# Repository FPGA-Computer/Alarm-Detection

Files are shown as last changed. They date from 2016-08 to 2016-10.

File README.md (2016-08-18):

"Alarm detection for hearing impaired"

This is the repository for this project.

Project page:
https://hackaday.io/project/12703

Schematic tool: Eagle CAD 6.5.0
3D modelling: Sketchup 14.1 2014

Licensing:
Schematic: Creative Commons 4.0 Attribution-ShareAlike 4.0 International
PCB & Layout: Creative Commons 4.0 Attribution-NonCommercial
3D modelling: Creative Commons 4.0 Attribution-ShareAlike 4.0 International

Creative Commons 4.0 Attribution-NonCommercial:
See http://creativecommons.org/licenses/by-nc/4.0/

Creative Commons 4.0 Attribution-ShareAlike 4.0 International
See http://creativecommons.org/licenses/by-sa/4.0/

Firmware license: GPL 3.0

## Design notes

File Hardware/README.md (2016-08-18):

"Alarm detection for hearing impaired"

Since the common block is useful for a few of my projects, 
I have splitted off the hardware design into smaller modular 
block for initial prototyping.

LCD Backpack: STM32F030 based PCB for mounting onto the back 
of a "Nokia" LCD.  It has anti-alias RC filter for ADC and an 
optional 3.3V boost mode power supply for running off two
Alkaline/NiMH batteries.

The firmware is based on the VU/Spectrum analyzer of the 
"Automatic-Audio-Switch".  I have increase the FFT resolution 
to about 37.5Hz and a bandwidth of 5kHz.

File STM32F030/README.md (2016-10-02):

Alarm detection for hearing impaired

"DMA mem func & reorg"
- use DMA for memset() and memmove()
- reorganize DMA, SPI calls from Nokia5110 into hardware.c
---------------------------------
"Visualization"
- added a simple graphic library
- added battery status and volume envelope
---------------------------------
"Lost in Space" pre-pre release
The PCB I have ordered has been lost in the mail.  This
is the 2nd one in a row and I don't know if/when they
would fix up the shipping.  This has major impact to the
schedule of this project.  Since there don't seem be much 
interest in this, I have decided to do an premptive
release of the firmware at the early stage.

Source code is under GPL3.0 with the following 3 files 
under their own licenses.

ST: startup_stm32f030.s
Elm-chan's: intfft.c, intfft.h

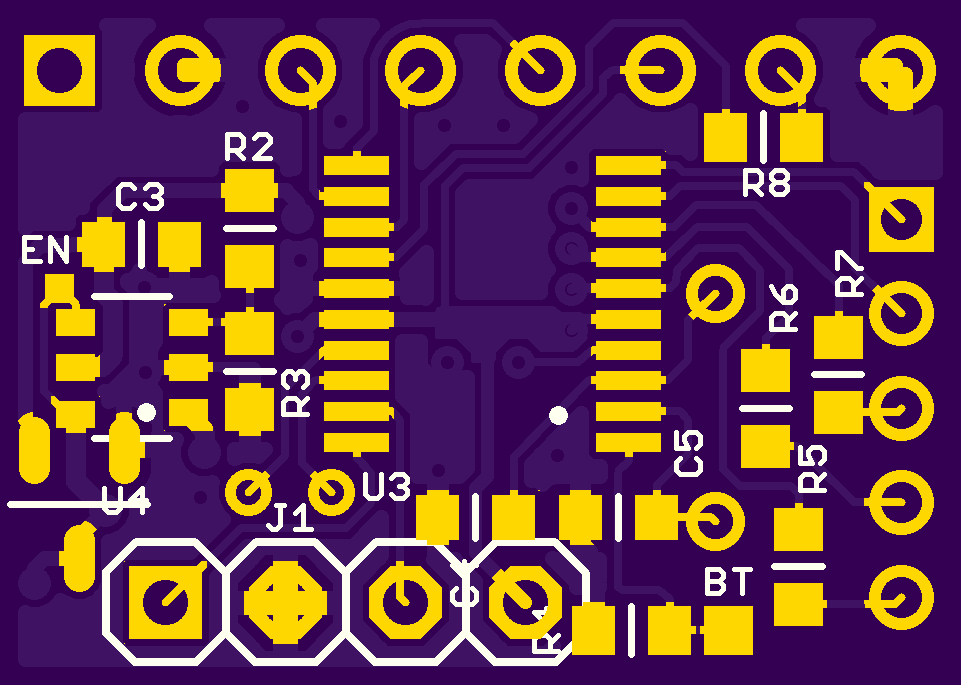
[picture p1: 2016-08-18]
Hardware/Prototype/LCD Backpack/eagleUp/eagleUp_alarm-v1_board_bottom.png

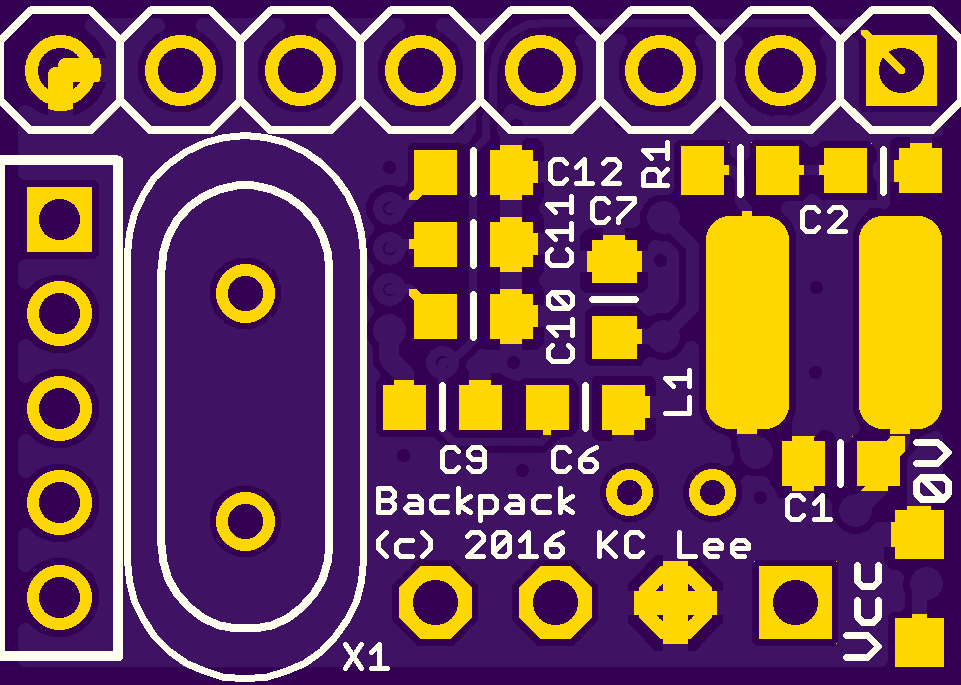
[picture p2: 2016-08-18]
Hardware/Prototype/LCD Backpack/eagleUp/eagleUp_alarm-v1_board_top.png

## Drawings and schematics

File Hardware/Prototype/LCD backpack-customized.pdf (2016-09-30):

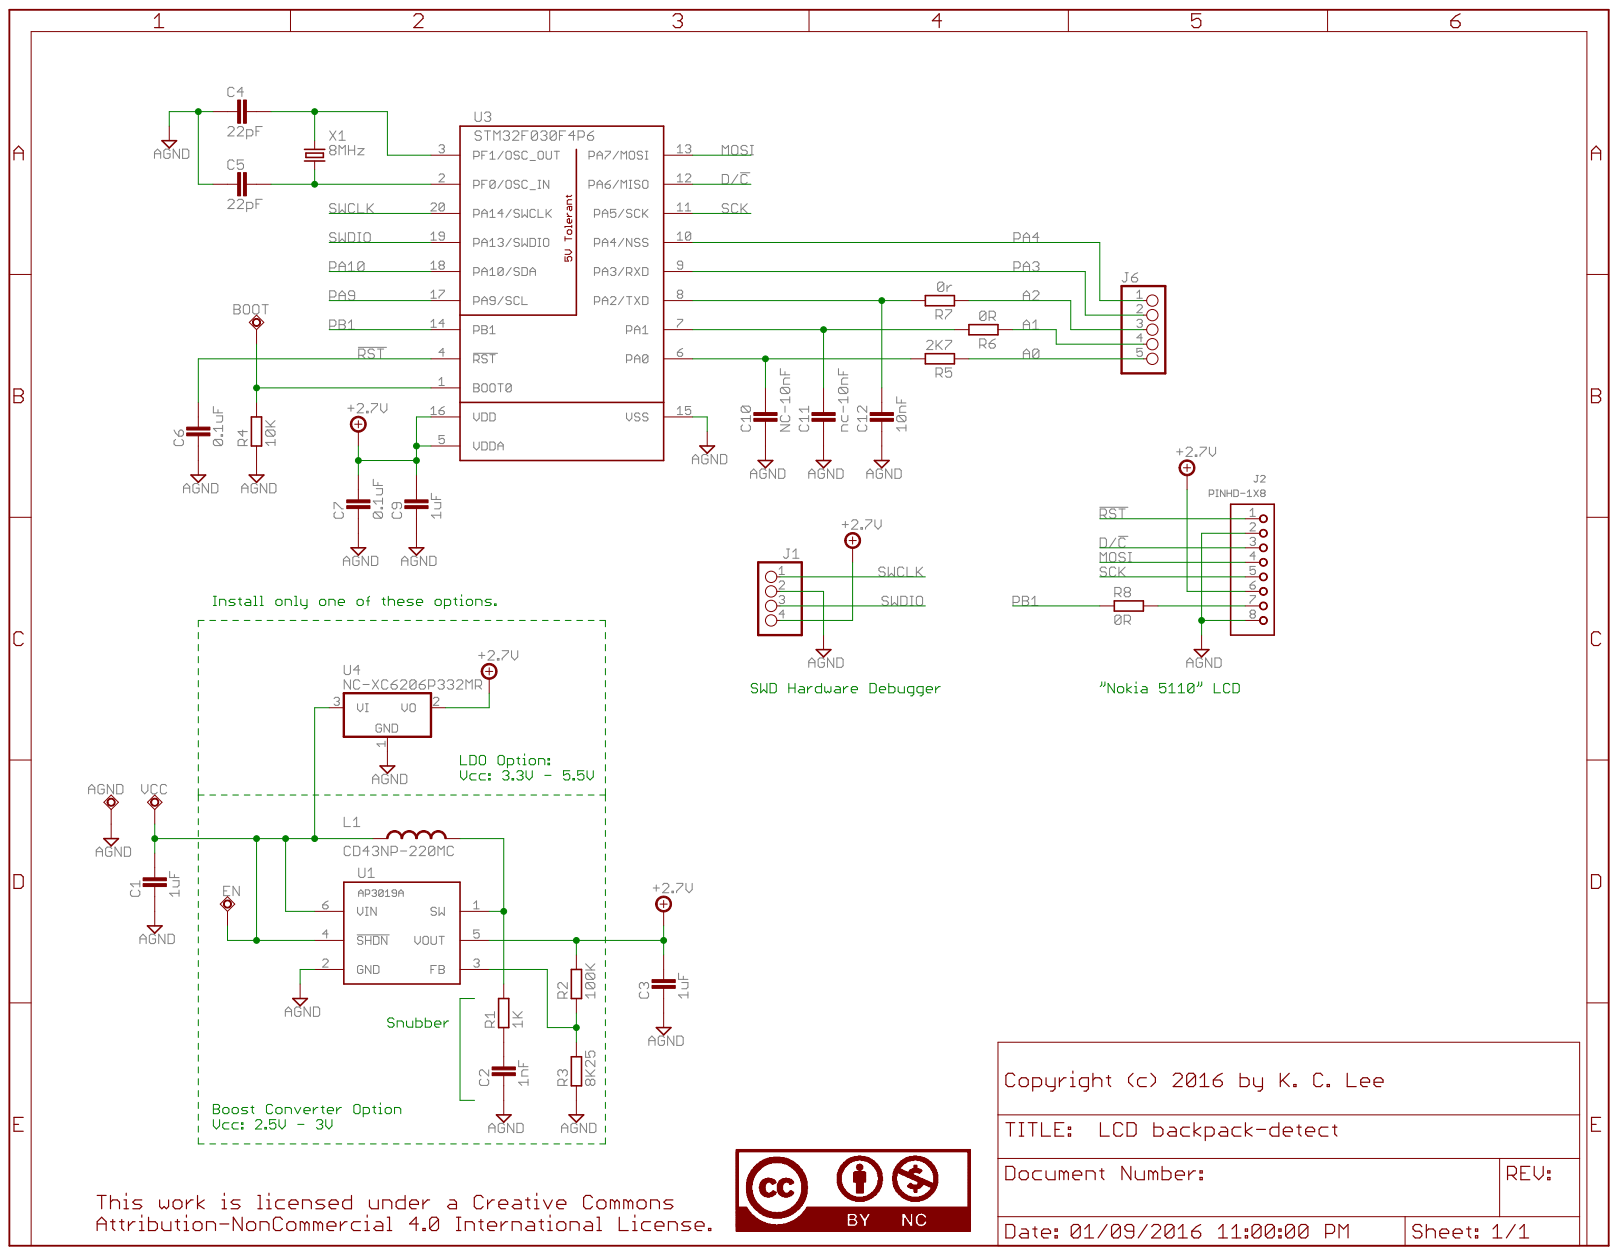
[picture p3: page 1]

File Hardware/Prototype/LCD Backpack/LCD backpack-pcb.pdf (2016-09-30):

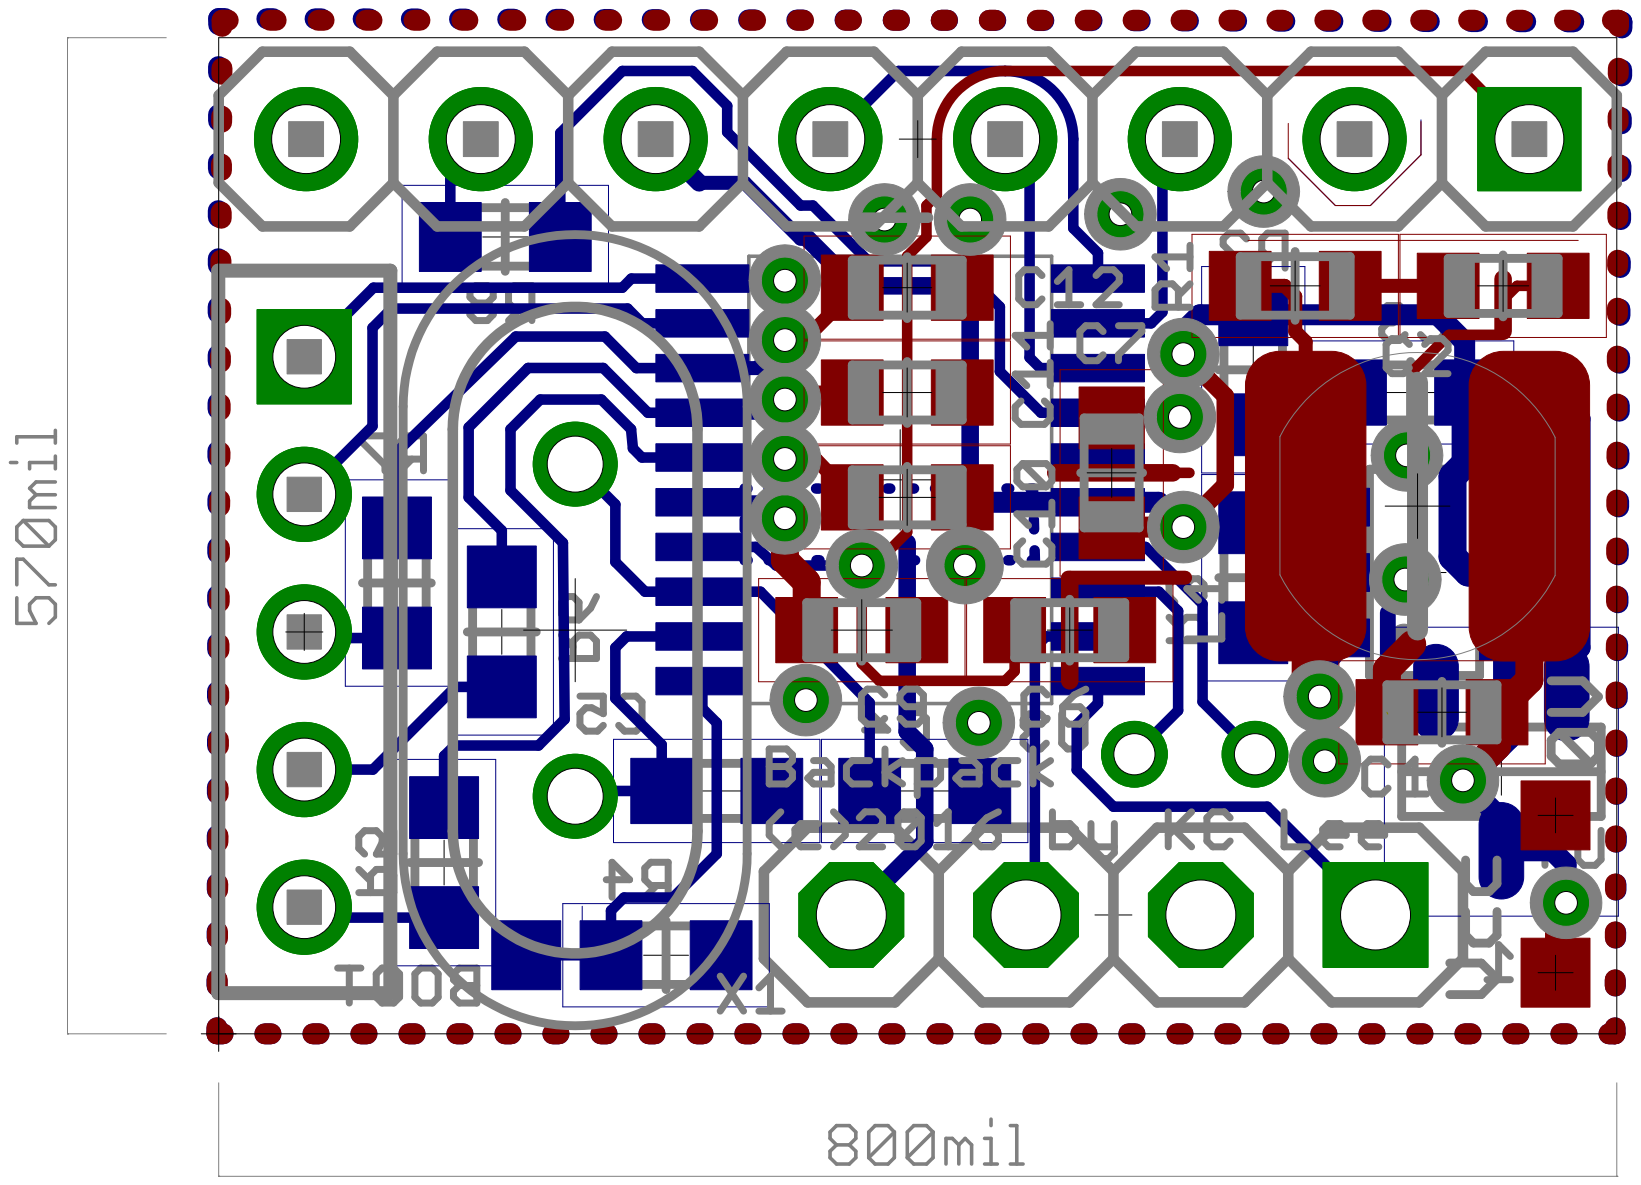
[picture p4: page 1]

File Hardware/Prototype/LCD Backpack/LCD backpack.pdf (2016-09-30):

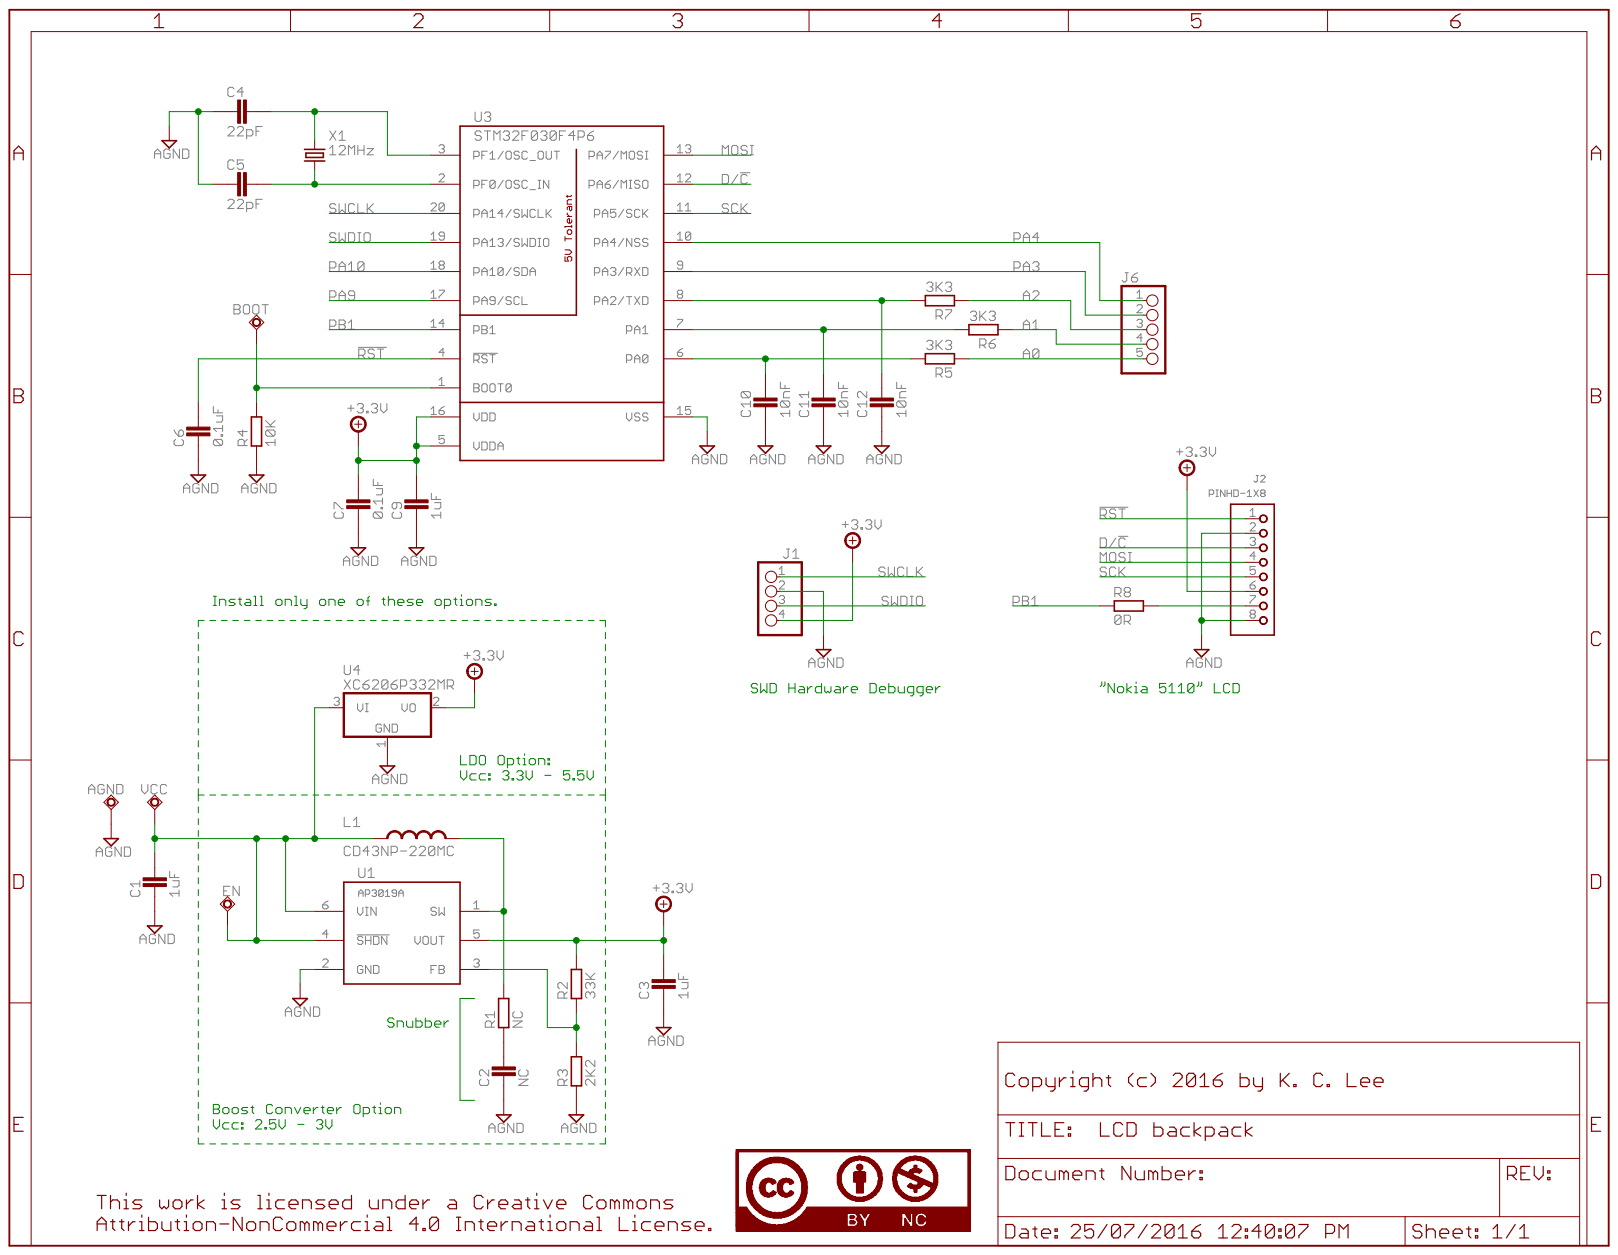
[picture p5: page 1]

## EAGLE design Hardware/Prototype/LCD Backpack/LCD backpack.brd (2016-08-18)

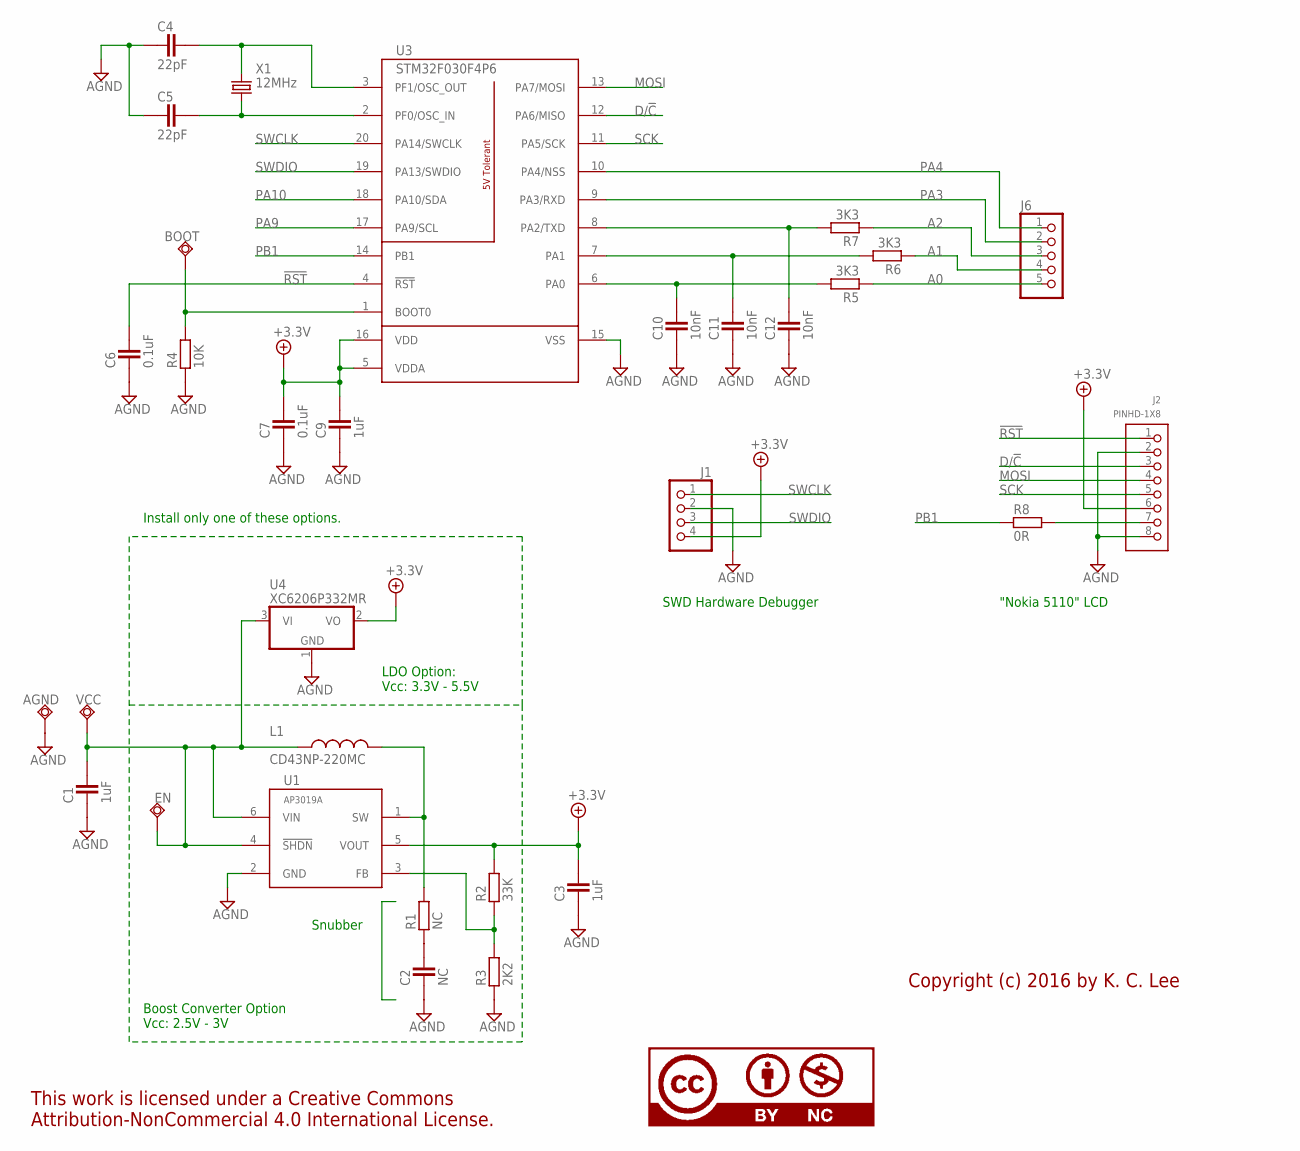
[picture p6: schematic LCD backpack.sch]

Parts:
AGND: TPSQTP10SQ; TP10SQ; PARTNO TESTPAD
BOOT: TPSQTP10SQ; TP10SQ; PARTNO TESTPAD
C1, C3, C9: 1uF; CAPC1608X92N; PARTNO STOCK: 1UF/10V 20% TDK
C2: NC; CAPC1608X92N; PARTNO *
C4, C5: 22pF; CAPC1608X92N; PARTNO *
C6, C7: 0.1uF; CAPC1608X92N; PARTNO *
C10, C11, C12: 10nF; CAPC1608X92N; PARTNO *
EN: TPSQTP06SQ; TP06SQ; PARTNO TESTPAD
J1: PINHD-1X4_2.54; 1X04; PARTNO 1x04 header 2.54mm
J2: PINHD-1X8; 1X08; PARTNO 1x08 header 2.54mm
J6: PINHD-1X5_2.00; 1X05M; PARTNO 1X5 header 2MM
L1: CD43NP-220MC; CD43; PARTNO DK: 587-1626-1-ND
LICENSE1: CC-BY-NCNONE; CC-NONE; PARTNO *
R1: NC; RESC1608X55N; PARTNO *
R2: 33K; RESC1608X55N; PARTNO *
R3: 2K2; RESC1608X55N; PARTNO *
R4: 10K; RESC1608X55N; PARTNO *
R5, R6, R7: 3K3; RESC1608X55N; PARTNO *
R8: 0R; RESC1608X55N; PARTNO *
U1: AP3019A; SOT26; PARTNO AP3019AKTR-G1
U3: STM32F030F4P6; TSSOP20; PARTNO *
U4: XC6206P332MR; SOT95P280X135-3N; PARTNO *
VCC: TPSQTP10SQ; TP10SQ; PARTNO TESTPAD
X1: 12MHz; HC49U-V; PARTNO *

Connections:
!RST: C6.2, J2.1, U3.4 (!RST)
+3.3V: C3.2, C7.2, C9.2, J1.4, J2.6, R2.2, U1.5 (VOUT), U3.5 (VDDA), U3.16 (VDD), U4.2 (VO)
A0: J6.5, R5.1
A1: J6.4, R6.1
A2: J6.3, R7.1
AGND: AGND.TP, C1.1, C2.1, C3.1, C4.1, C5.1, C6.1, C7.1, C9.1, C10.1, C11.1, C12.1, J1.2, J2.2, J2.8, R3.1, R4.1, U1.2 (GND), U3.15 (VSS), U4.1 (GND)
BUTTON: C12.2, R7.2, U3.8 (PA2/TXD)
D/!C: J2.3, U3.12 (PA6/MISO)
MOSI: J2.4, U3.13 (PA7/MOSI)
unnamed: C2.2, R1.1
unnamed: J2.7, R8.2
unnamed: L1.1, R1.2, U1.1 (SW)
unnamed: R2.1, R3.2, U1.3 (FB)
unnamed: BOOT.TP, R4.2, U3.1 (BOOT0)
unnamed: C10.2, R5.2, U3.6 (PA0)
unnamed: C11.2, R6.2, U3.7 (PA1)
unnamed: C5.2, U3.2 (PF0/OSC_IN), X1.1
unnamed: C4.2, U3.3 (PF1/OSC_OUT), X1.2
PA3: J6.2, U3.9 (PA3/RXD)
PA4: J6.1, U3.10 (PA4/NSS)
PA9: U3.17 (PA9/SCL)
PA10: U3.18 (PA10/SDA)
PB1: R8.1, U3.14 (PB1)
SCK: J2.5, U3.11 (PA5/SCK)
SWCLK: J1.1, U3.20 (PA14/SWCLK)
SWDIO: J1.3, U3.19 (PA13/SWDIO)
VCC: C1.2, EN.TP, L1.2, U1.4 (!SHDN), U1.6 (VIN), U4.3 (VI), VCC.TP

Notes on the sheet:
SWD Hardware Debugger
Copyright (c) 2016 by K. C. Lee
Snubber
Boost Converter Option Vcc: 2.5V - 3V
LDO Option: Vcc: 3.3V - 5.5V
Install only one of these options.
"Nokia 5110" LCD

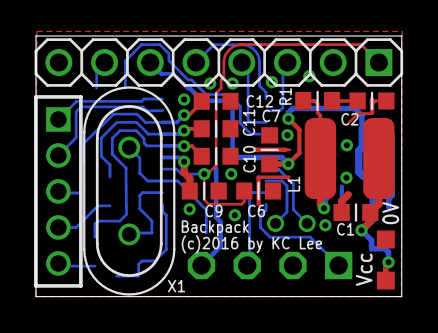
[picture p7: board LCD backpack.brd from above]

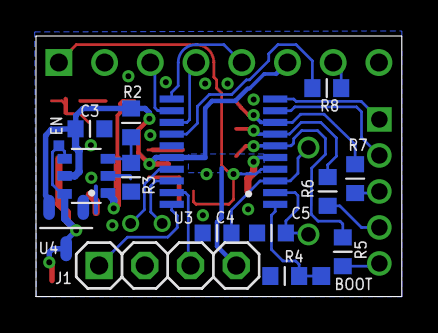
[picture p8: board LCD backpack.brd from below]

Board: 2 copper layers, 20.3 x 14.5 mm, 32 parts (16 on the bottom side), 25 nets.

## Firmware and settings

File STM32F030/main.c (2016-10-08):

/*
 * main.c
 *
 * Created: June-16-16, 8:38:27 AM
 *  Author: K. C. Lee
 * Copyright (c) 2016 by K. C. Lee
 
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
	If not, see http://www.gnu.org/licenses/gpl-3.0.en.html
 */ 

#include "hardware.h"
#include "font.h"

uint8_t Ticks;

int main(void)
{ 
	Hardware_Init();
	Audio_Init();
	ADC_Start();
	
	__WFI( 	);	
	while(1)
	{	
		if(Audio_Data.Conv_Done)
		{
			Audio_Data.Conv_Done = 0;
			
			Audio_Processing();
			UpdateDisplay();
			__WFI( 	);
		}
	}
}

void UpdateDisplay(void)
{
	if(Ticks)
		Ticks--;
	else
	{
		Ticks = TICK_RELOAD;
		Plot_All();
	}
}

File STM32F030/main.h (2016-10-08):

/*
 * hardware.h
 *
 * Created: July-10-16, 4:09:33 PM
 *  Author: K. C. Lee
 * Copyright (c) 2016 by K. C. Lee 
 
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
	If not, see http://www.gnu.org/licenses/gpl-3.0.en.html
 */ 

#ifndef _MAIN_H_
#define _MAIN_H_

#include <stdint.h>
#include "stm32f0xx.h"
#include "core_cm0.h"
#include <string.h>

void Task_Update_Volume(void);
void Task_ADC_Sample(void);
void UpdateTime(void);
void UpdateDisplay(void);
void ChangeDisplayMode(uint8_t Mode);
void Update_AudioSource(void);
void Draw_AudioSource_Label(void);
extern uint8_t Ticks;

// DC offset averages
#define OFFSET_PERIOD					64
// Battery voltage averages ideally 2^n
#define ADC_BATT_AVERAGES			8

// Volume average time in ms
#define VOLUME_AVERAGE_PERIOD	300UL
// Peak volume decay time in ms
#define PEAK_VOLUME_DECAY			1500UL

#define ADC_AUDIO_SAMPLES			512UL
#define ADC_BLOCK_SIZE				(ADC_AUDIO_SAMPLES/2)

// FFT size = 256
#define	N_FFT									ADC_BLOCK_SIZE

// 8MHz/781 = 10243
#define ADC_SAMPLE_RATE				10240UL
#define ADC_SAMPLE_PERIOD			(CPU_CLOCK/ADC_SAMPLE_RATE)

// 40Hz
#define ADC_DMA_RATE					(ADC_SAMPLE_RATE/ADC_BLOCK_SIZE)
#define PEAK_DECAY_RATE				((PEAK_VOLUME_DECAY*ADC_DMA_RATE)/1000UL)
#define SCREEN_REFRESH_RATE		10UL
#define TICK_RELOAD						(ADC_DMA_RATE/SCREEN_REFRESH_RATE)
		
#define AUDIO_THRESHOLD 			0x260

#define PLOTDATA_ROW					1
#define PLOTDATA_ROWS					5

#define SPECTRUM_ROW					4
#define SPECTRUM_COL					0
#define SPECTRUM_ROWS					3
#define SPECTRUM_WIDTH				((SPECTRUM_BIN-SPECTRUM_START)/2)

#define SPECTRUM_GRID_ROW			(SPECTRUM_ROW-SPECTRUM_ROWS+1)
#define SPECTRUM_GRID_LONG		0x06
#define SPECTRUM_GRID_SHORT		0x02

#define SPECTRUM_START				1
#define SPECTRUM_BIN					(ADC_BLOCK_SIZE/2) 
#define SPECTRUM_BIN_INC			(SPECTRUM_BIN/SPECTRUM_WIDTH)
#define SPECTRUM_BIN_FREQ			(ADC_SAMPLE_RATE/N_FFT)

#define RMS_NOISE_COL					(SPECTRUM_WIDTH+3)
#define RMS_NOISE_DASH_WIDTH	2
#define RMS_NOISE_SPACE_WIDTH	1

#define VU_ROW								4
#define VU_COL								(LCD_MAX_X-(VU_WIDTH+1))
#define VU_WIDTH							5
#define VU_ROWS								4

#define VOLUME_COL						0
#define VOLUME_COLS						1
#define VOLUME_ROW						1
#define VOLUME_ROWS						2
#define VOLUME_WIDTH					(64/VOLUME_COLS)

#define BATT_ROW							0
#define BATT_COL							(SPECTRUM_WIDTH+3)
#define BATT_BAT_WIDTH				(LCD_MAX_X - BATT_COL)
#define BATT_BM								0x40
#define BATT_LOW_END					2300
#define BATT_BAR_RES					30

#define STATUS_FREQ_COL				0
#define STATUS_FREQ_ROW				0
#define FREQ_START						3

#define FREQ_THRESHOLD				5

#define BACKLIGHT_TIMEOUT			40
#endif

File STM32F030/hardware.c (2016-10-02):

/*
 * hardware.c
 *
 * Created: June-16-16, 8:38:27 AM
 *  Author: K. C. Lee
 * Copyright (c) 2016 by K. C. Lee
 
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
	If not, see http://www.gnu.org/licenses/gpl-3.0.en.html
 */
 
#include "hardware.h"
 
void Hardware_Init(void)
{
	// Enable GPIO, DMA
	RCC->AHBENR |= RCC_AHBENR_GPIOAEN|RCC_AHBENR_GPIOBEN|RCC_AHBENR_GPIOFEN|RCC_AHBENR_DMAEN;
	// Enable SPI, SYSCFG, DBGMCU, TIM16
	RCC->APB2ENR |= RCC_APB2ENR_SYSCFGCOMPEN|RCC_APB2ENR_DBGMCUEN|RCC_APB2ENR_TIM16EN;
	
	// Assign GPIOA functions
	GPIOA->MODER = GPIOA_MODER;
	GPIOA->AFR[1] = GPIOA_AFR1;

	// PB1 = Output
	GPIOB->BSRR = PIN_SET(BACKLIGHT);
	GPIOB->MODER = PIN_OUTPUT(PB1);
	
	RCC->APB2ENR |= RCC_APB2ENR_SPI1EN;
	
	// SPI Master, Software NSS, Slave select, MSB first, 
	// SCK=8MHz/2=4MHz, CPOL=0, CHPA=0
	SPI1->CR1 = SPI_CR1_MSTR|SPI_CR1_SSM|SPI_CR1_SSI|SPI_BR;
	
	// Data size = 8-bit, Motorola SPI mode, No NSS
	SPI1->CR2 = SPI_CR2_DS_2|SPI_CR2_DS_1|SPI_CR2_DS_0|SPI_CR2_TXDMAEN;	

	// Enable SPI
	SPI1->CR1|= SPI_CR1_SPE;
	
	// DMA Ch3 - SPI
	DMA1_Channel3->CPAR = (uint32_t) &SPI1->DR;  
	
	NVIC_SetPriority(DMA1_Ch2_3_DMA2_Ch1_2_IRQn,LCD_DMA_IRQ_PRIORITY);
  NVIC_EnableIRQ(DMA1_Ch2_3_DMA2_Ch1_2_IRQn);
	
	LCD_Init();
	ADC_Init();
}

volatile uint8_t SPI_Wait, Mem_Wait;

void DMA1_Channel2_3_IRQHandler(void)
{
	if(DMA1->ISR & DMA_ISR_TCIF3)
	{	
		DMA1->IFCR = DMA_IFCR_CTCIF3;
		SPI_Wait = 0;
	}
	if(DMA1->ISR & DMA_ISR_TCIF2)
	{	
		DMA1->IFCR = DMA_IFCR_CTCIF2;
		Mem_Wait = 0;
	}
}

void SPI_DMA_Wait(void)
{
	while(SPI_Wait)
		__WFI();
  
  // wait until SPI finishes
  while(SPI1->SR & SPI_SR_BSY)
    /* wait */ ;
}

void SPI_Block_Fill(uint8_t Fill, uint16_t size)
{
  DMA1_Channel3->CCR = 0;
  DMA1_Channel3->CMAR = (uint32_t) &Fill;
  DMA1_Channel3->CNDTR = size;
  SPI_Wait = 1;
	
  // 8-bit memory/peripheral, write, enable
  DMA1_Channel3->CCR = SPI_DMA_PRIORITY|DMA_CCR_DIR|DMA_CCR_TCIE|DMA_CCR_EN;
  SPI_DMA_Wait();  
}

void SPI_Block_Write(const uint8_t *ptr, uint16_t size)
{
  DMA1_Channel3->CCR = 0;
  DMA1_Channel3->CMAR = (uint32_t) ptr;
  DMA1_Channel3->CNDTR = size;
  SPI_Wait = 1;
	
  // 8-bit memory/peripheral, memory increment, write, enable, complete IRQ
  DMA1_Channel3->CCR = SPI_DMA_PRIORITY|DMA_CCR_MINC|DMA_CCR_DIR|DMA_CCR_TCIE|DMA_CCR_EN;
  SPI_DMA_Wait();  
}

void SPI_ByteWrite(uint8_t byte)
{
  SPI_Block_Write(&byte,1);
}

// async assending memmove using DMA - not 100% compatible
void DMA_memmove(void *Dst, void *Src, uint16_t Size)
{
  DMA1_Channel2->CCR = 0;
  DMA1_Channel2->CMAR = (uint32_t)Src;
	DMA1_Channel2->CPAR = (uint32_t)Dst;
  DMA1_Channel2->CNDTR = Size;
	
	// Memory to memory mode, 8-bit, low priority, increment
  DMA1_Channel2->CCR = DMA_CCR_EN|DMA_CCR_MEM2MEM|DMA_CCR_PINC|DMA_CCR_MINC|DMA_CCR_DIR|DMA_CCR_TCIE;
}

void DMA_memset(void *Dst, uint8_t fill, uint16_t Size)
{
  DMA1_Channel2->CCR = 0;
  DMA1_Channel2->CMAR = (uint32_t)&fill;
	DMA1_Channel2->CPAR = (uint32_t)Dst;
  DMA1_Channel2->CNDTR = Size;
	Mem_Wait = 1;
	
	// Memory to memory mode, 8-bit, low priority, increment
  DMA1_Channel2->CCR = DMA_CCR_EN|DMA_CCR_MEM2MEM|DMA_CCR_PINC|DMA_CCR_DIR|DMA_CCR_TCIE;
	
	while(Mem_Wait)
		__WFI();
}

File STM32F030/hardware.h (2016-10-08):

/*
 * hardware.h
 *
 * Created: March-14-16, 4:52:17 PM
 *  Author: K. C. Lee
 * Copyright (c) 2016 by K. C. Lee 
 
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
	If not, see http://www.gnu.org/licenses/gpl-3.0.en.html
 */ 

#ifndef _HARDWARE_H_
#define _HARDWARE_H_

#include "main.h"
#include "gpio.h"

#define MIN(X,Y)							(((X)<=(Y))?(X):(Y))

#define CPU_CLOCK							8000000UL
#define UART_BAUD							115200

#define HSE_CLOCK							8000000UL

// SCK = Clk/2 = 4MHz
#define SPI_BR								0

#define LCD_DMA_IRQ_PRIORITY	3

// Enable Debug shell 
//#define DBG_SHELL
#undef DBG_SHELL

//#define ADC_RES_8
#define ADC_RES_12

#define BACKLIGHT							PB1
#define LCD_DC								PA6
#define ADC_BATT_IN						PA1
#define ADC_MIC_IN						PA0

#define ADC_SRC_GROUP					(1<<ADC_MIC_IN)
#define ADC_BATTERY						(1<<ADC_BATT_IN)

#define ADC_AVERAGES					(VOLUME_AVERAGE_PERIOD*ADC_SAMPLE_RATE/ADC_BLOCK_SIZE/1000)
#define ADC_BATT_SCALE_MULT		2505UL
#define ADC_BATT_SCALE_DIV		2509UL

// Max # of audio source
#define ADC_MAX_SRC						1
// L/R channels
#define ADC_CH_PER_SRC				1
#define ADC_MAX_AUD_CH				1
// Max # of channels per conversion
#define ADC_MAX_CH						ADC_MAX_AUD_CH

#include "main.h"
#include "nokia5110.h"
#include "adc.h"
#include "audio.h"
//#include "fifo.h"

void Hardware_Init(void);

enum ADC_Chs
{
	Audio_R1, Audio_L1, Audio_R0, Audio_L0, Buttons
};

#define GPIOA_MODER (PIN_ALT(PA14)|PIN_ALT(PA13)|				/* SWCLK, SWDIO */	\
										 PIN_OUTPUT(PA10)|PIN_OUTPUT(PA9)|	/* CTRL1, CTRL0	*/	\
										 PIN_ALT(PA7)|PIN_OUTPUT(PA6)|			/* MOSI, D/C 		*/	\
										 PIN_ALT(PA5)|PIN_OUTPUT(PA4)|			/* SCK, ???			*/	\
										 PIN_OUTPUT(PA3)|PIN_OUTPUT(PA2)|		/* ???, ???			*/	\
		                 PIN_ANALOG(PA1)|PIN_ANALOG(PA0))		/* ???, Analog in	*/
										 
#define CTRL1				PA3
#define CTRL0				PA2

#define GPIOA_AFR1	0

// low priority
#define SPI_DMA_PRIORITY    0

void SPI_Block_Write(const uint8_t *ptr, uint16_t size);
void SPI_Block_Fill(uint8_t Fill, uint16_t size);

void SPI_ByteWrite(uint8_t byte);

void DMA_memmove(void *Dst, void *Src, uint16_t Size);
void DMA_memset(void *Dst, uint8_t fill, uint16_t Size);
#endif

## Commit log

2016-08-18 Lost in space - initial commit
    [LCD backpack.brd, LCD backpack.sch]
2016-10-02 DMA mem func & reorg

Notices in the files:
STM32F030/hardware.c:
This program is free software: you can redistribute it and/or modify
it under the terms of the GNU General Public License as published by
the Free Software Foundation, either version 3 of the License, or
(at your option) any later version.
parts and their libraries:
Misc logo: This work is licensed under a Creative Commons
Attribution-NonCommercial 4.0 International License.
